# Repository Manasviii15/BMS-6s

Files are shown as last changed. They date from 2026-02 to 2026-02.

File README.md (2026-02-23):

# Smart Battery Management System — Design Package
**Version:** 1.0 | **Date:** 2026 | **Classification:** Engineering Reference

## Package Contents

```
BMS_Design_Package/
├── README.md                          ← This file
├── Schematic/
│   ├── BMS_Schematic_Rev1.0.pdf       ← Full schematic (PDF, print-ready)
│   └── BMS_Schematic_Rev1.0.png       ← Schematic image (high-res)
├── PCB_Layout/
│   ├── BMS_PCB_Layout_Rev1.0.pdf      ← PCB layout top+bottom views (PDF)
│   └── BMS_PCB_Layout_Rev1.0.png      ← PCB layout image (high-res)
├── Gerbers/
│   ├── Top_Copper/    BMS-F_Cu.gbr    ← L1: Signal + Component pads
│   ├── Inner_Layers/  BMS-In1_Cu.gbr  ← L2: Ground plane
│   │                  BMS-In2_Cu.gbr  ← L3: Power distribution
│   ├── Bottom_Copper/ BMS-B_Cu.gbr    ← L4: High-current traces
│   ├── Silkscreen/    BMS-F_SilkS.gbr ← Component labels
│   │                  BMS-B_SilkS.gbr
│   ├── Soldermask/    BMS-F_Mask.gbr  ← Solder mask openings
│   │                  BMS-B_Mask.gbr
│   ├── Paste/         BMS-F_Paste.gbr ← Stencil openings (SMD pads)
│   └── Drill/         BMS-PTH.drl     ← Plated through-hole drill file
│                      BMS-NPTH.drl    ← Non-plated drill (mounting holes)
├── BOM/
│   └── BMS_BOM_Rev1.0.csv             ← Full Bill of Materials (CSV)
├── Netlist/
│   └── BMS_Netlist.net                ← Netlist (KiCad format)
└── KiCad_Project/
    ├── BMS.kicad_pro                  ← KiCad project file
    ├── BMS.kicad_sch                  ← KiCad schematic stub
    └── BMS.kicad_pcb                  ← KiCad PCB stub
```

## PCB Specifications

| Parameter | Value |
|---|---|
| Board dimensions | 160 mm × 110 mm |
| Layer count | 4 |
| Substrate | FR4, Tg 150°C |
| Board thickness | 1.6 mm |
| Copper weights | L1: 1 oz / L2: 1 oz / L3: 2 oz / L4: 3 oz |
| Min trace/space | 0.15 mm / 0.15 mm (signal), 8 mm (power) |
| Min drill | 0.3 mm (vias), 3.2 mm (mounting holes) |
| Surface finish | ENIG (Electroless Nickel Immersion Gold) |
| Solder mask | Green LPI, both sides |
| Silkscreen | White epoxy, both sides |
| Impedance control | 50 Ω (CAN differential pair) |
| Max working voltage | 60 V |
| Max continuous current | 70 A (main path, L4 traces) |

## Design Rules Summary

### High-Current Path (L4 Bottom Copper - 3oz)
- Main power traces: 8 mm wide minimum
- Current rating: ≥85 A at 20°C rise (IPC-2221)
- Via stitching: 20× vias minimum through all layers for current transitions

### Signal Path (L1 Top Copper - 1oz)  
- Signal traces: 0.2 mm standard, 0.15 mm minimum
- CAN differential pair: 0.25 mm, matched length ±0.5 mm
- I2C: 0.2 mm, with 100 pF distributed capacitance limit

### Thermal Management
- MOSFET (Q1-Q8): Thermal vias to L3 copper pour, 4 mm grid, 0.8 mm drill
- AFE IC (U1): Exposed pad soldered to L2 GND via, 6× 0.5 mm vias
- LDO (U7): Thermal slug on bottom, stitched to GND pour

## Ordering Instructions (JLCPCB / PCBWay)

1. Upload Gerbers ZIP → Select **4-layer**
2. Dimensions: 160 × 110 mm
3. Quantity: 5–10 (prototype)
4. Layer stackup: JLC04161H-7628 (or equivalent)
5. Cu thickness: Specify 1/1/2/3 oz (non-standard — confirm with fab)
6. Surface finish: **ENIG**
7. Solder mask: Green
8. Request impedance test coupon (50 Ω)

## Critical Notes

⚠️ **High voltage warning**: Pack voltage up to 26.1V (6S), max 60V transient
⚠️ **High current**: 70A continuous, 300A short-circuit. Use proper fusing.
⚠️ **ESD sensitive**: U1, U2, U3 are ESD sensitive. Handle with ESD precautions.
⚠️ **Pre-charge**: Always use pre-charge circuit before connecting capacitive loads.

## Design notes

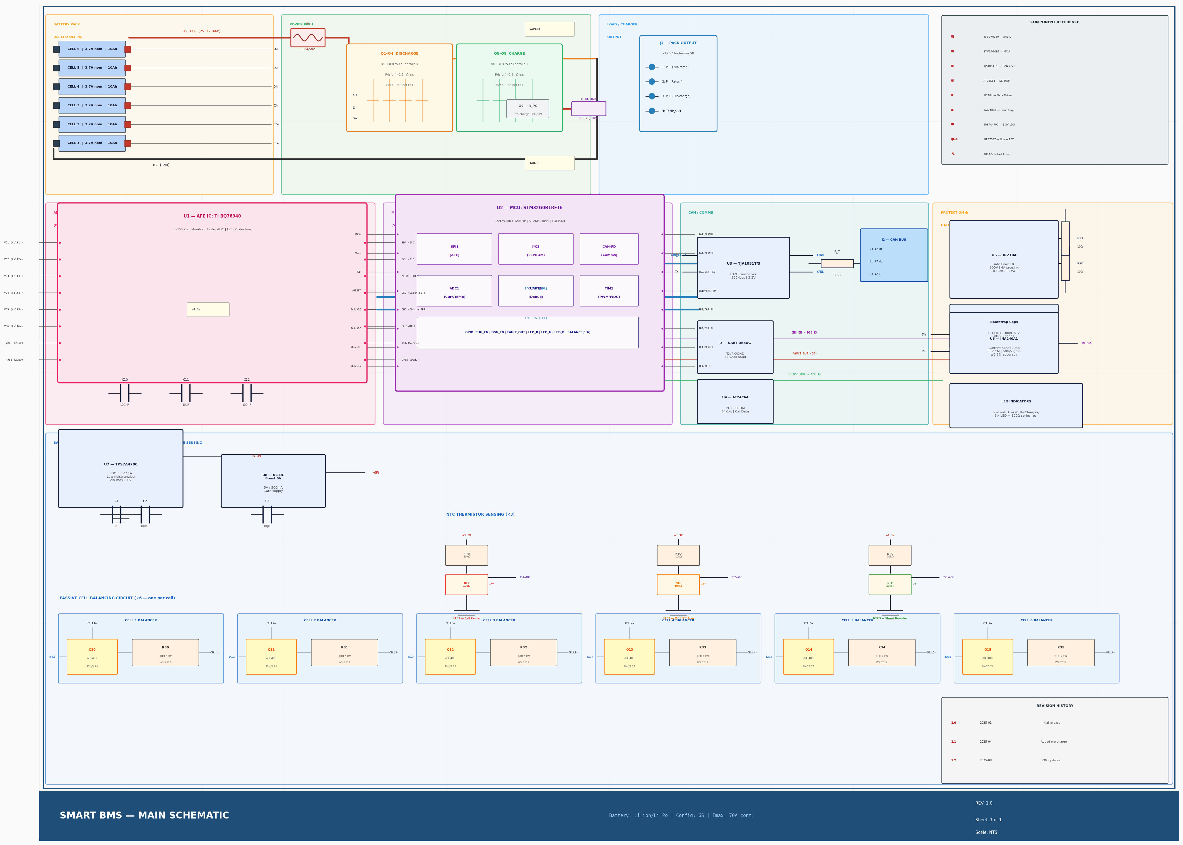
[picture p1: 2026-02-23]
Schematic/BMS_Schematic_Rev1.0.png

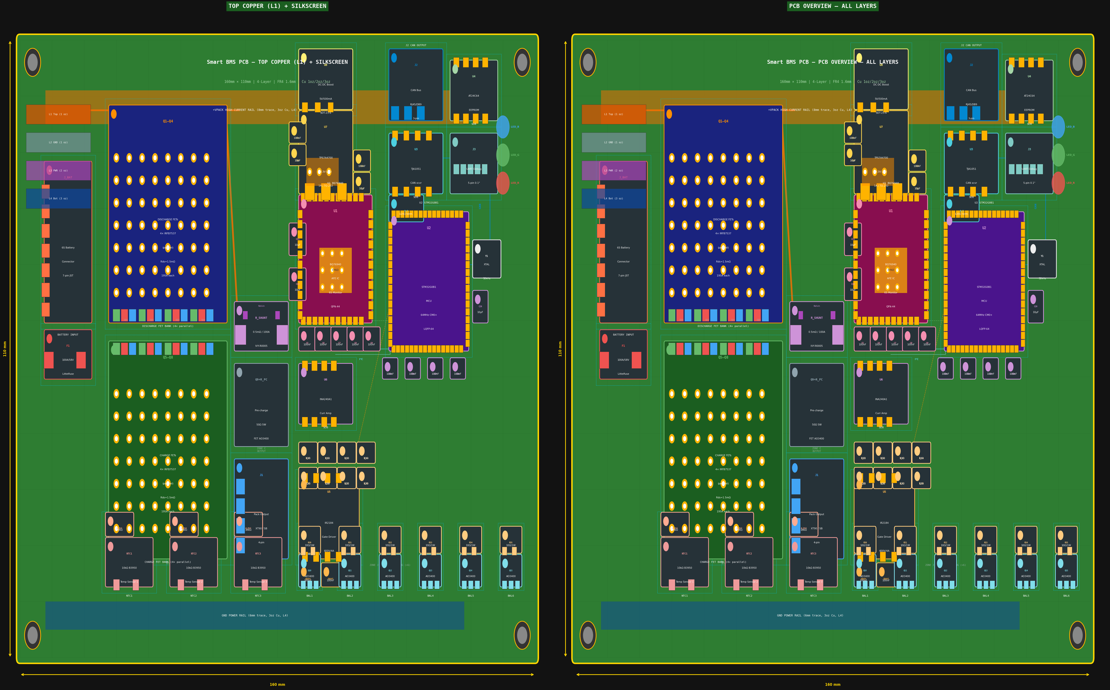
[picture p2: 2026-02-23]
PCB_Layout/BMS_PCB_Layout_Rev1.0.png

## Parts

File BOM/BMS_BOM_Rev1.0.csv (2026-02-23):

RefDes | Qty | Value | Description | Package | Manufacturer | Part Number | Digikey PN | Unit Price USD | Extended USD
U1 | 1 | BQ76940 | 6-15S AFE IC Battery Monitor 12-bit ADC I2C | QFN-44 7x7mm | Texas Instruments | BQ76940PFBR | 296-38930-1-ND | 8.50 | 8.50
U2 | 1 | STM32G0B1RET6 | ARM Cortex-M0+ 64MHz 512KB Flash CAN-FD LQFP-64 | LQFP-64 | STMicroelectronics | STM32G0B1RET6 | 497-STM32G0B1RET6-ND | 6.80 | 6.80
U3 | 1 | TJA1051T/3 | CAN Bus Transceiver 5Mbps 3.3V SO-8 | SO-8 | NXP Semiconductors | TJA1051T/3/1J | TJA1051T/3/1J-ND | 1.25 | 1.25
U4 | 1 | AT24C64C-SSHM-T | I2C EEPROM 64Kbit 1MHz SO-8 | SO-8 | Microchip Technology | AT24C64C-SSHM-T | AT24C64C-SSHM-TCT-ND | 0.65 | 0.65
U5 | 2 | IR2184STRPBF | Half-Bridge Gate Driver 600V 4A SO-8 | SO-8 | Infineon | IR2184STRPBF | IR2184STRPBFCT-ND | 2.30 | 4.60
U6 | 1 | INA240A1PWR | Current Sense Amplifier 80V 50V/V TSSOP-8 | TSSOP-8 | Texas Instruments | INA240A1PWR | INA240A1PWRCT-ND | 2.75 | 2.75
U7 | 1 | TPS7A4700RGWT | LDO Regulator 3.3V 1A Low-Noise QFN-20 | QFN-20 | Texas Instruments | TPS7A4700RGWT | TPS7A4700RGWTCT-ND | 4.20 | 4.20
U8 | 1 | TPS61032PWPR | Boost Converter 5V 500mA TSSOP-14 | TSSOP-14 | Texas Instruments | TPS61032PWPR | TPS61032PWPRCT-ND | 2.90 | 2.90
Q1-Q8 | 8 | IRFB7537PBF | N-Channel MOSFET 75V 195A Rds(on)=1.5mΩ TO-220AB | TO-220AB | Vishay Siliconix | IRFB7537PBF | IRFB7537PBF-ND | 3.80 | 30.40
Q9 | 1 | IRLB8721PBF | N-Channel MOSFET 30V 62A Pre-charge TO-220AB | TO-220AB | Vishay | IRLB8721PBF | IRLB8721PBF-ND | 1.20 | 1.20
Q10-Q15 | 6 | AO3400 | N-Channel MOSFET 30V 5.7A Balance switch SOT-23 | SOT-23 | Alpha & Omega | AO3400A | AO3400A-ND | 0.30 | 1.80
R_SHUNT | 1 | IVY-R0005-1.0 | 4-Terminal Shunt 0.5mΩ 100A 1% 2512 | 4-Terminal 2512 | Isabellenhuette | IVY-R0005-1.0 | IVY-R0005-1.0-ND | 8.50 | 8.50
R1-R4 | 4 | PC_SHUNT 10Ω | Pre-charge & Gate resistor 10Ω 1W 1% | 1206 | Vishay | CRCW120610R0FKEA | 541-10KHCT-ND | 0.15 | 0.60
R5-R10 | 6 | 10Ω 1W | Balancing resistor 10Ω 1W 1% pulse-rated 2512 | 2512 | Vishay | WSL25121L000FEA18 | WSL25121L000FEA18CT-ND | 0.55 | 3.30
R_G1-R_G8 | 8 | 10Ω 0603 | Gate resistor 10Ω 0.1W 1% | 0603 | Yageo | RC0603FR-0710RL | 311-10.0HRCT-ND | 0.05 | 0.40
R_PU1-R_PU3 | 3 | 10kΩ 0603 | NTC pull-up 10kΩ 0.1W 1% | 0603 | Yageo | RC0603FR-0710KL | 311-10.0KHRCT-ND | 0.05 | 0.15
R_T | 1 | 120Ω 0603 | CAN bus termination 120Ω 0.1W 1% | 0603 | Yageo | RC0603FR-07120RL | 311-120HRCT-ND | 0.05 | 0.05
C1-C4 | 4 | 10µF 50V | Bulk decoupling electrolytic 10µF 50V 20% | Radial 5mm | Panasonic | EEU-FC1H100 | P10330-ND | 0.35 | 1.40
C5-C20 | 16 | 100nF 25V | Bypass ceramic 100nF 25V X7R | 0402 | Murata | GRM155R71E104KA87D | 490-1524-1-ND | 0.05 | 0.80
C21-C24 | 4 | 10µF 16V | MCU/AFE decoupling ceramic 10µF 16V X5R | 0805 | TDK | C2012X5R1C106K125AB | 445-1417-1-ND | 0.15 | 0.60
C_BOOT1-C_BOOT2 | 2 | 100nF 100V | Gate driver bootstrap 100nF 100V X7R | 0805 | Murata | GRM21BR72A104KA35L | 490-3285-1-ND | 0.20 | 0.40
NTC1-NTC3 | 3 | B57164K103J | NTC Thermistor 10kΩ @ 25°C B=3977K | Radial 2.54mm | TDK | B57164K103J | 495-2167-ND | 0.60 | 1.80
F1 | 1 | 0498100 100A | Fast-blow fuse 100A 58V automotive | 5x20mm | Littelfuse | 0498100.MXP | F2520-ND | 3.50 | 3.50
J_BAT | 1 | B7B-XH-AM | 6S battery tap connector 7-pin XH 2.5mm | XH-2.5mm 7P | JST | B7B-XH-AM | 455-2265-ND | 0.85 | 0.85
J1 | 1 | XT90-M | Pack output connector 90A XT90 | XT90 | Amass | XT90-M | — | 1.50 | 1.50
J2 | 1 | CANH/CANL 3-pin | CAN bus output terminal block 5.08mm | 3-pin 5.08mm | Phoenix Contact | 1935174 | 277-1651-ND | 1.20 | 1.20
J3 | 1 | 5-pin 0.1 header | UART debug header 5-pin 2.54mm | 2.54mm 5P | Sullins | PRPC005SAAN-RC | S1012EC-05-ND | 0.30 | 0.30
LED_R | 1 | LTST-C191KRKT | LED Red 620nm 10mcd 0402 | 0402 | Lite-On | LTST-C191KRKT | 160-1427-1-ND | 0.15 | 0.15
LED_G | 1 | LTST-C191KGKT | LED Green 569nm 10mcd 0402 | 0402 | Lite-On | LTST-C191KGKT | 160-1432-1-ND | 0.15 | 0.15
LED_B | 1 | LTST-C191TBKT | LED Blue 466nm 5mcd 0402 | 0402 | Lite-On | LTST-C191TBKT | 160-1446-1-ND | 0.15 | 0.15
Y1 | 1 | ABS25-32.768KHZ | Crystal 32.768kHz ±20ppm SMD 3225 | SMD 3225 | Abracon | ABS25-32.768KHZ-T | 535-10250-1-ND | 0.80 | 0.80
TOTALS |  |  |  |  |  |  |  | BOM Subtotal: | $90.45
 |  |  |  |  |  |  |  | PCB (qty 5 ENIG 4-layer): | $85.00
 |  |  |  |  |  |  |  | Assembly estimate: | $120.00
 |  |  |  |  |  |  |  | Total per board (prototype): | $295.45

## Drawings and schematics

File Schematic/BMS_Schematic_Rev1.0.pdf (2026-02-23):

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

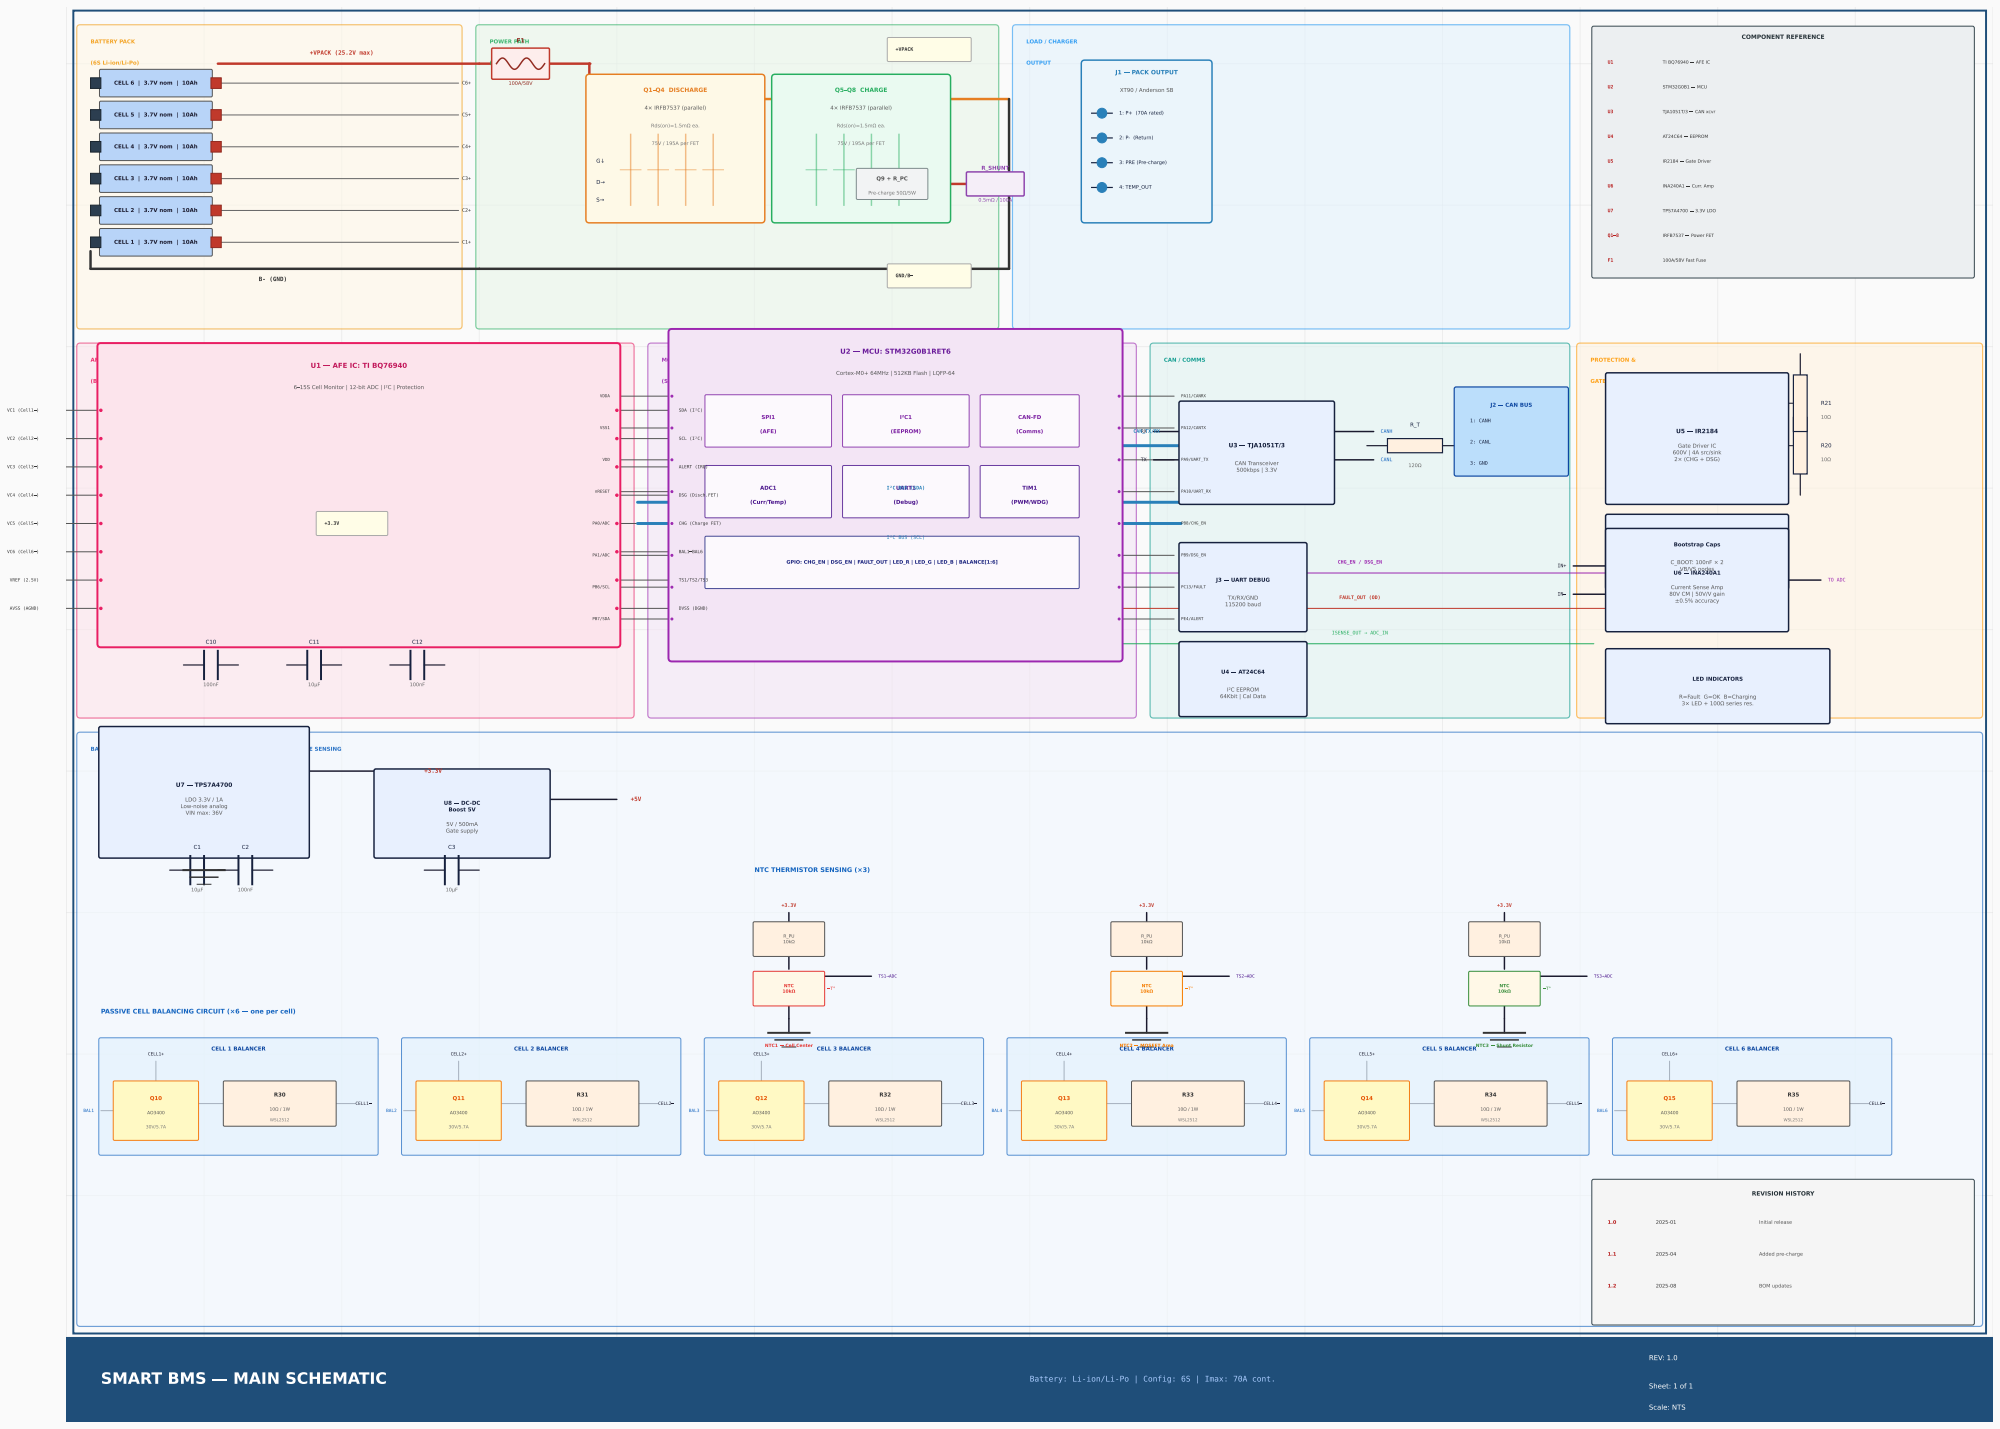
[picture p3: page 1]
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

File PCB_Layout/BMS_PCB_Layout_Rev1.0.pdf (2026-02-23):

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

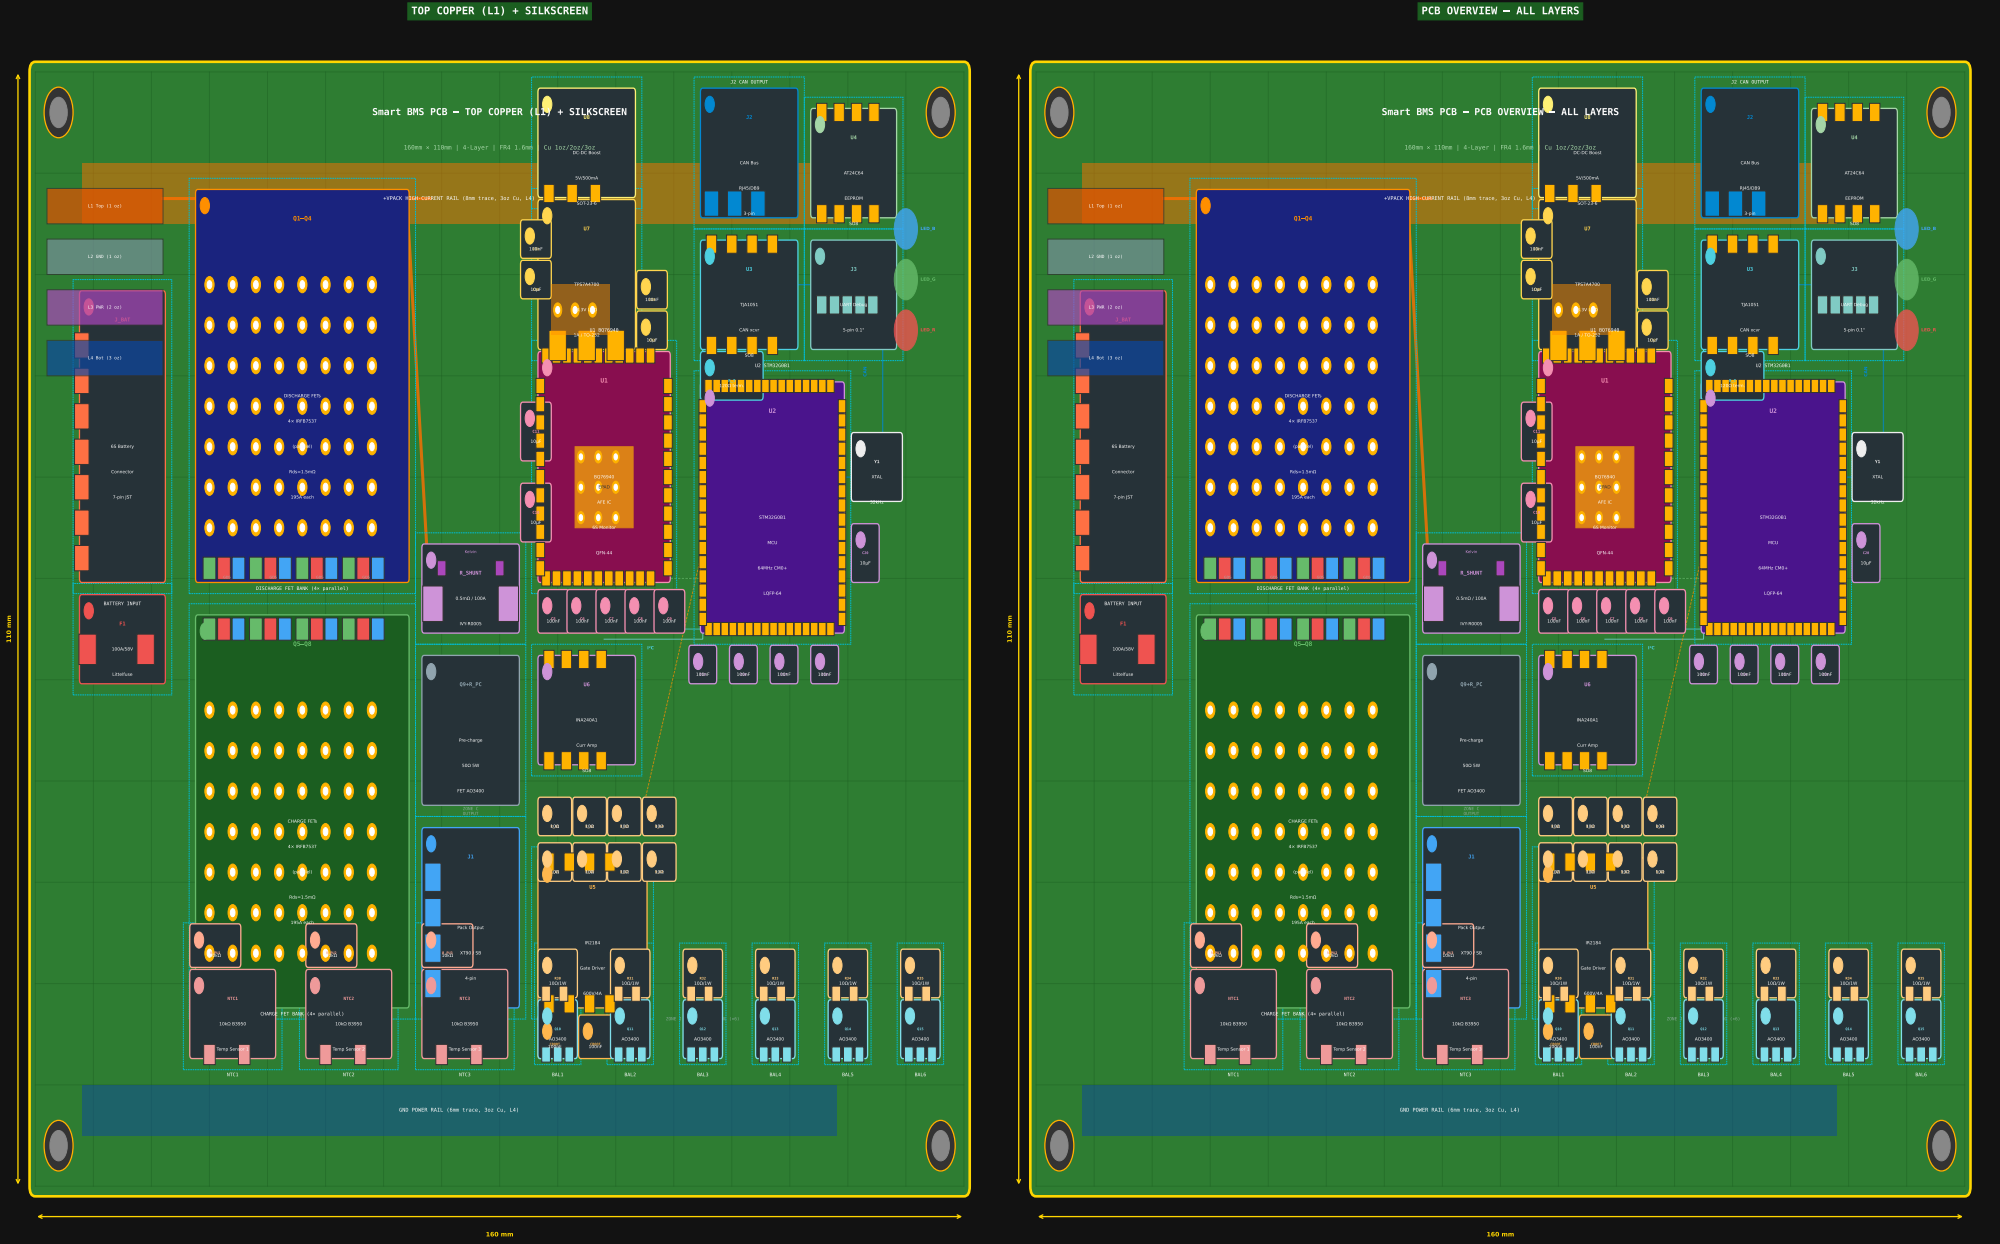
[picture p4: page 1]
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
